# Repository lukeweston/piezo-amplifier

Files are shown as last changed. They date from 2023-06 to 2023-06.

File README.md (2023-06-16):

3-channel piezoelectric nanopositioning amplifier

Adapted from the design of Hwu et al, with a few small changes.

https://www.sciencedirect.com/science/article/pii/S2468067222000621#f0085

Changed to a commercially manufactured 2-layer PCB, as 2-layer professional PCBs are incredibly cheap and easily available today.
Made the PCB a little more compact.

Changed power amplifier ICs to LM1875 as they are more readily available.
Heatsinks need to be screwed onto the LM1875 amplifier tabs.

Changed to SMA connectors directly on the board, to more easily connect the outputs directly to the board.

Avoiding SMD components as much as possible, as science students (who aren't electronics specialists) often struggle with them.

PCB is 100mm x 80mm, 2 layers. Standard, cheap design rules like 6 thou / 6 thou will work fine.

The Zip file in this repo contains a standard, fabrication-ready set of Gerber files for a fab such as OSHPark or PCBWay.

Board and schematic (.brd / .sch files) are in Autodesk Eagle format.

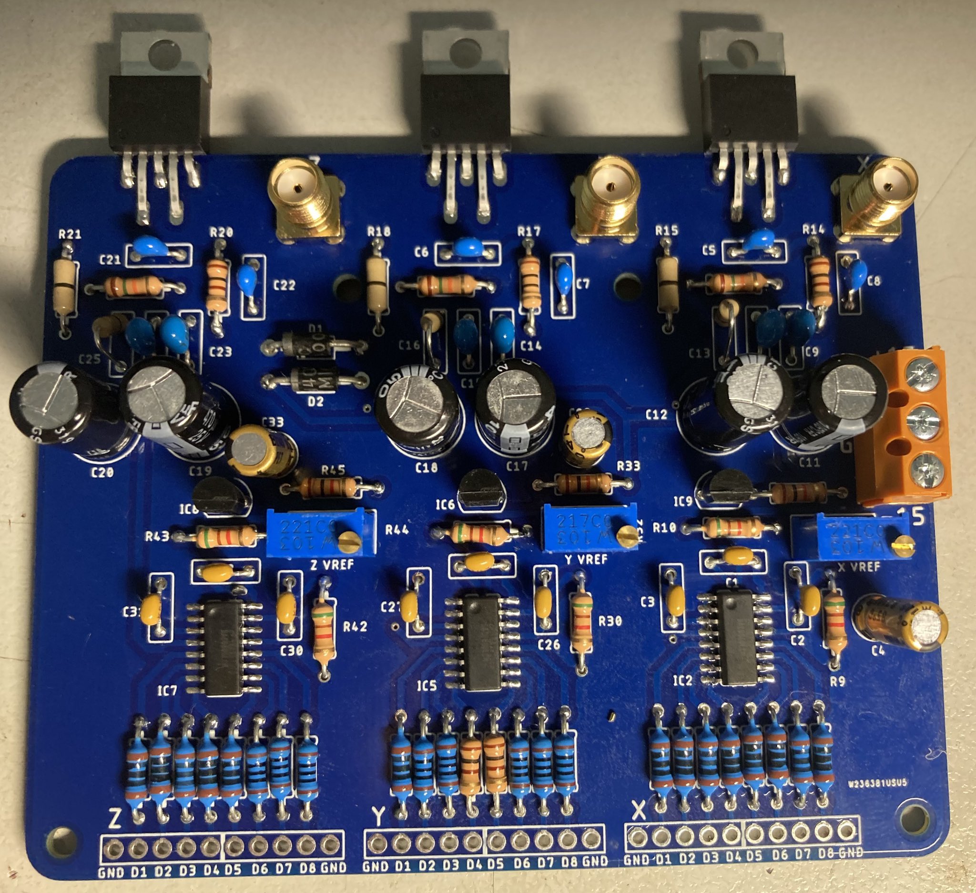
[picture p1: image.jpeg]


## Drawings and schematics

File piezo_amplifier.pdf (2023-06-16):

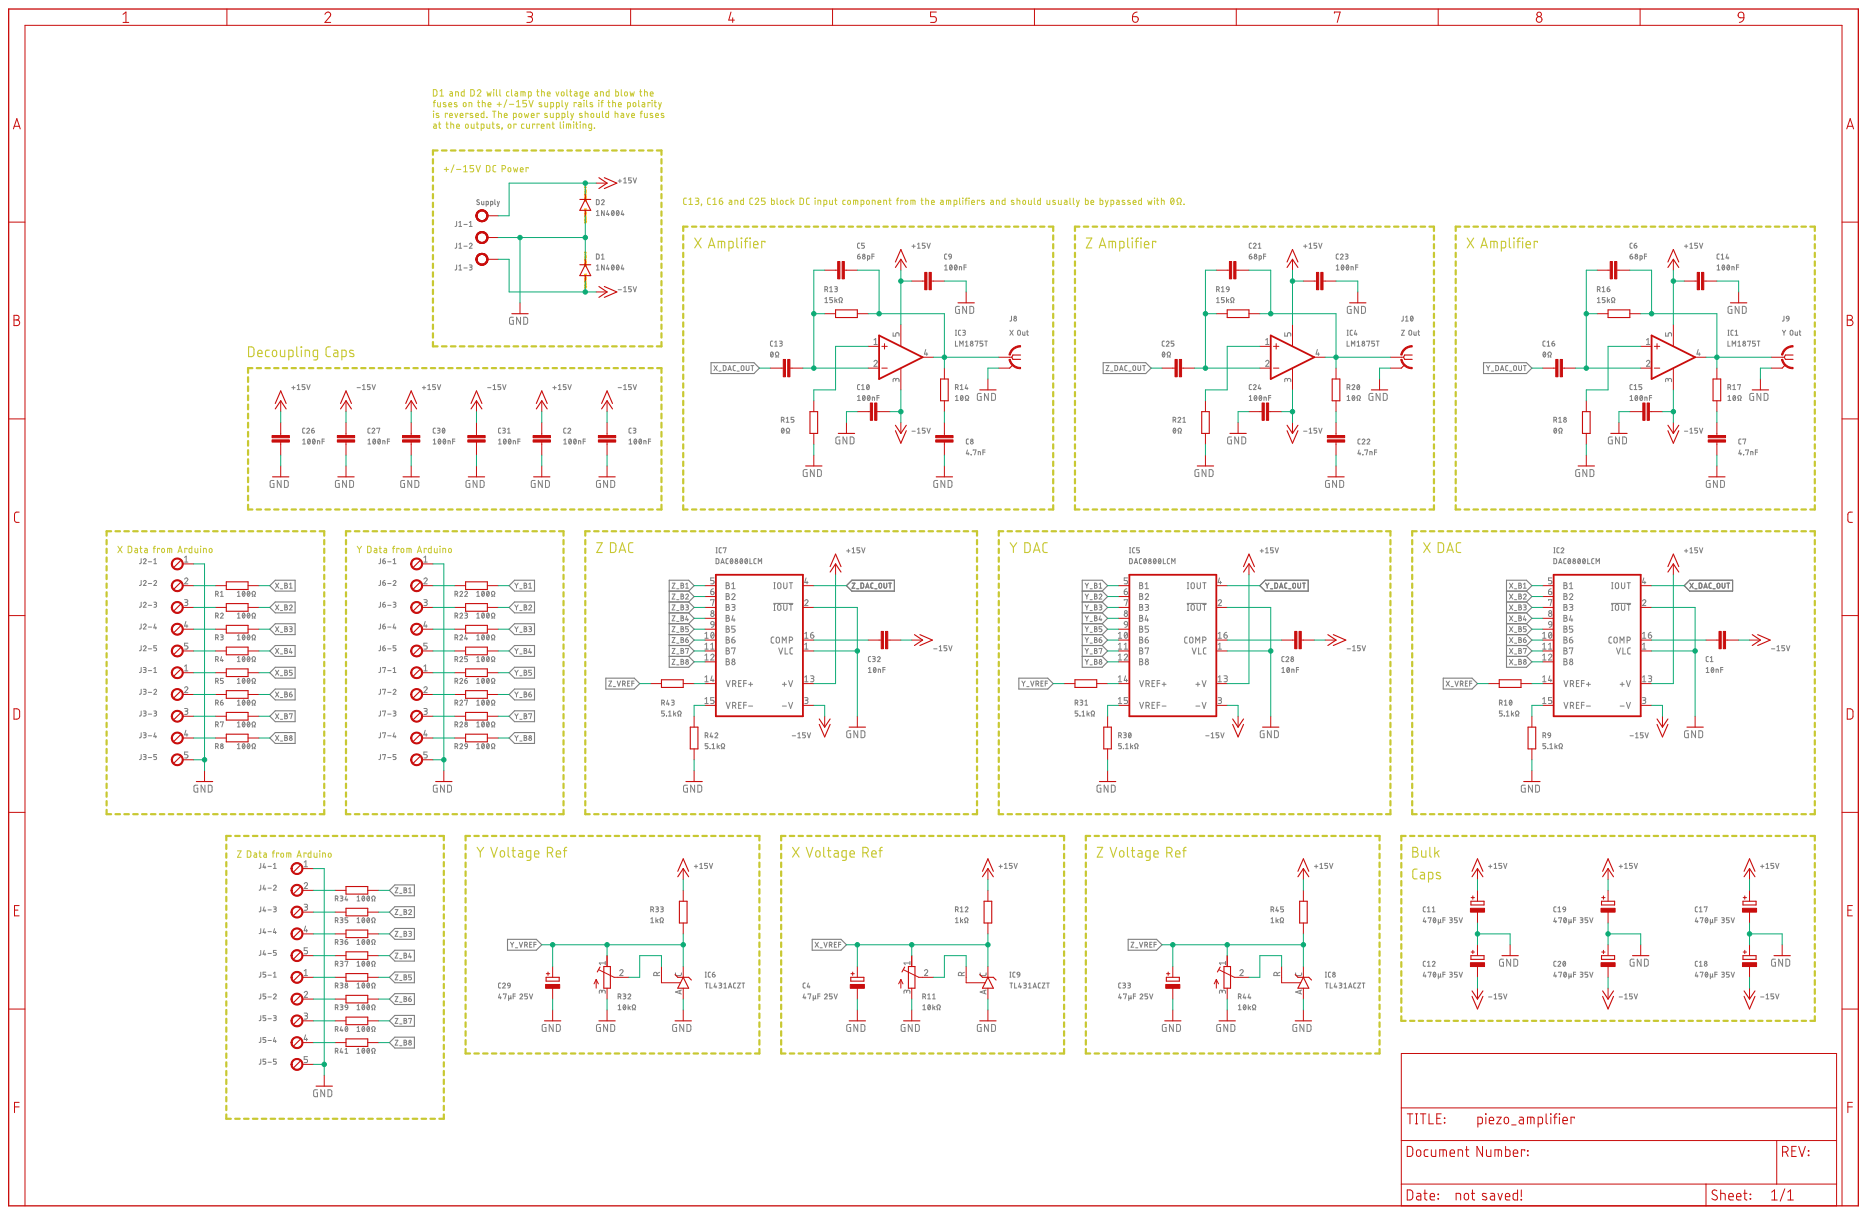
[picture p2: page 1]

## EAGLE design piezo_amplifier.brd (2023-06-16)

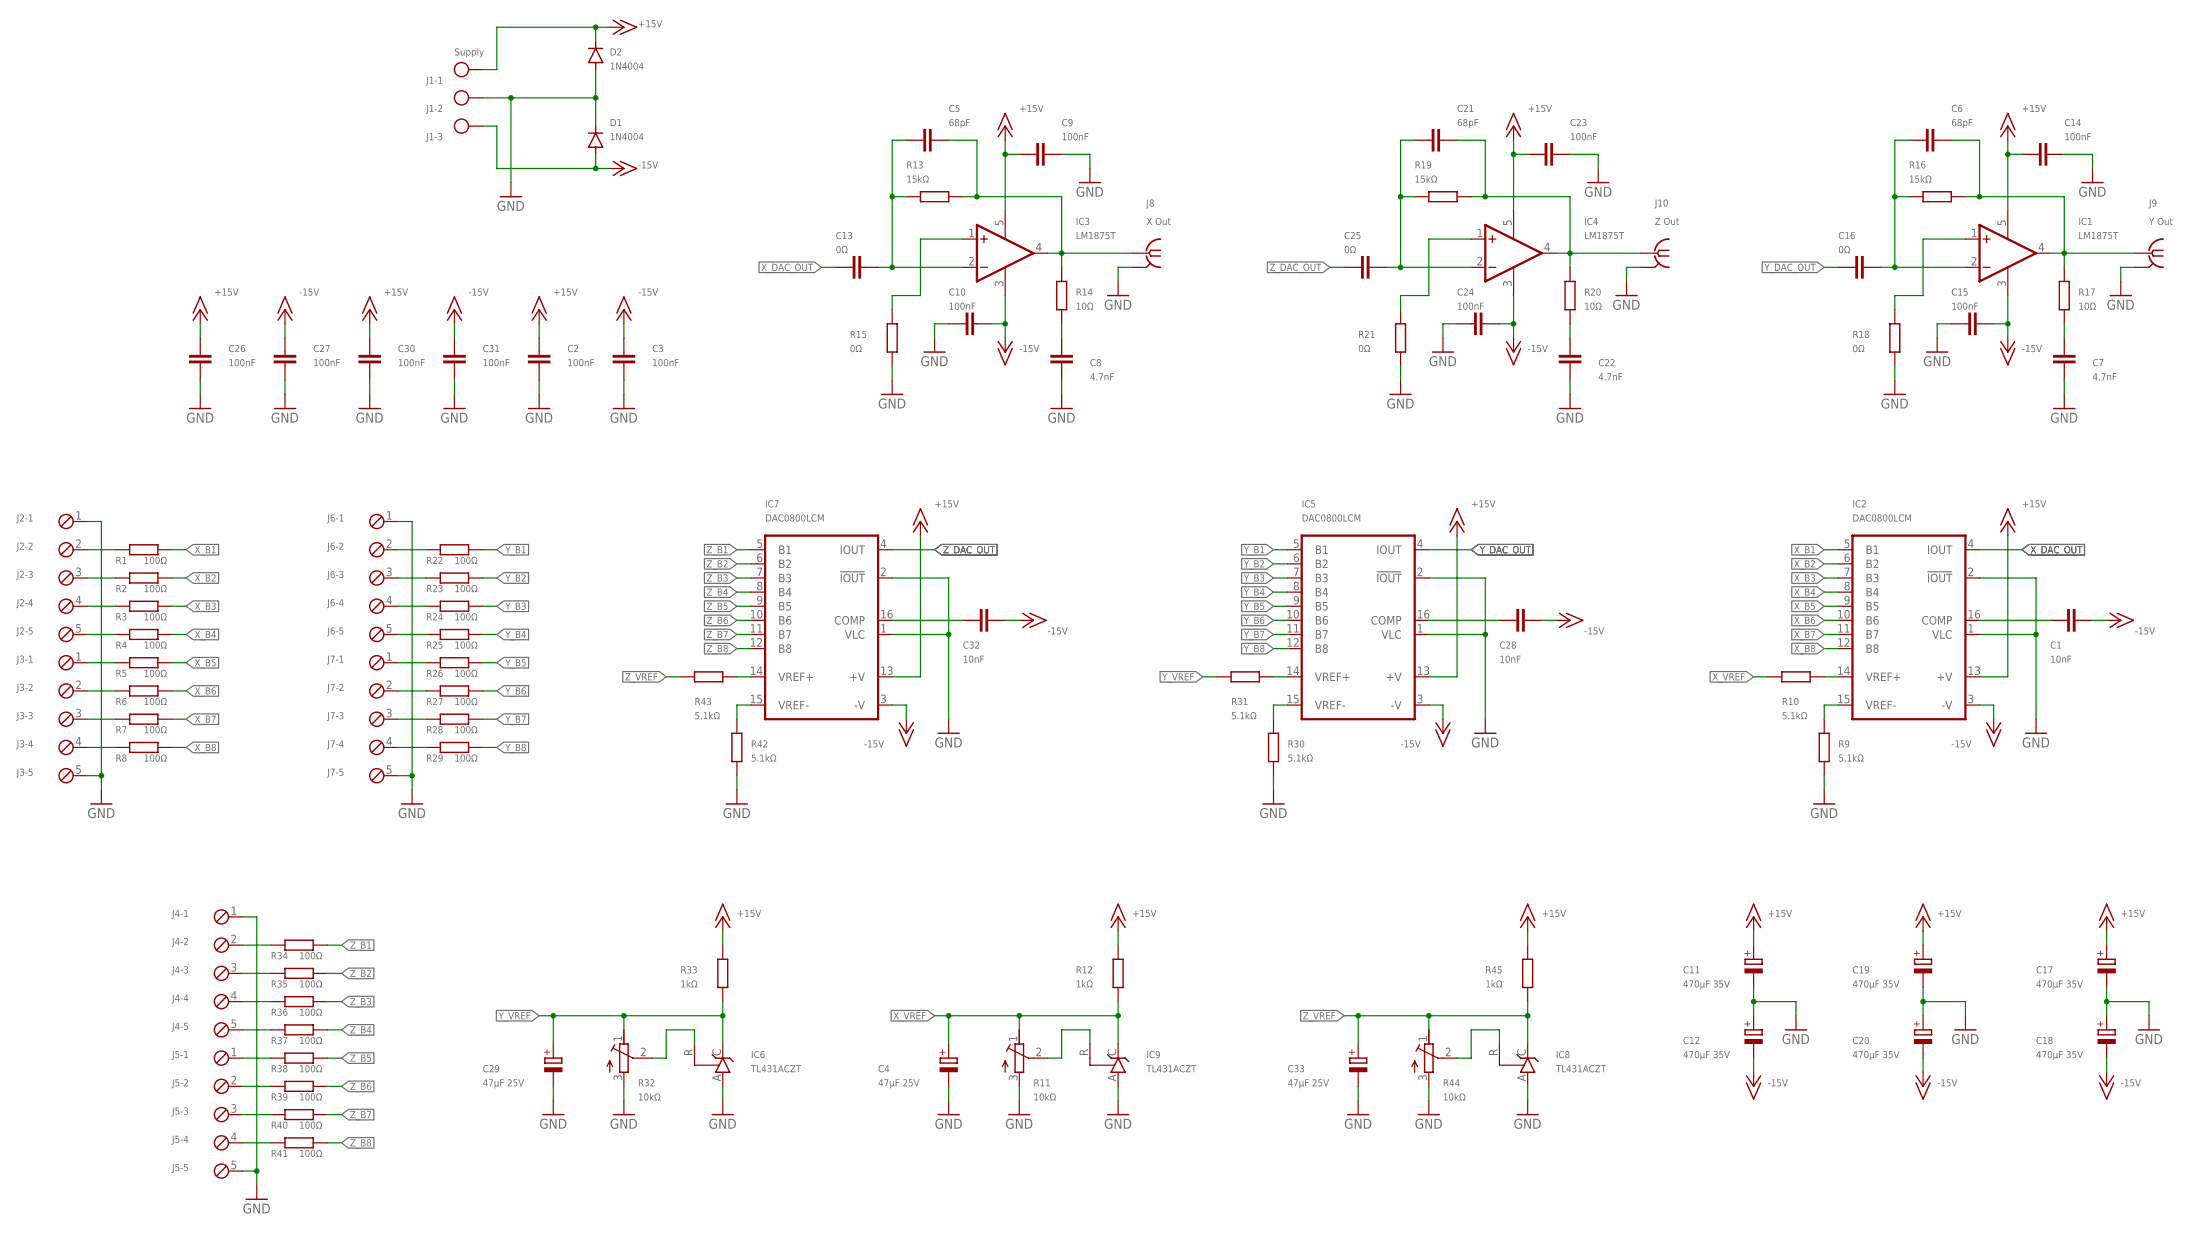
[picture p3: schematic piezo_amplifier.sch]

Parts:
C1, C28, C32: 10nF; C050-025X075
C2, C3, C9, C10, C14, C15, C23, C24, C26, C27, C30, C31: 100nF; C050-025X075
C4, C29, C33: 47µF 25V; E2,5-5
C5, C6, C21: 68pF; C050-025X075
C7, C8, C22: 4.7nF; C050-025X075
C11, C12, C17, C18, C19, C20: 470µF 35V; E5-8,5
C13, C16, C25: 0Ω; C050-025X075
D1, D2: 1N4004; DO41-10
IC1, IC3, IC4: LM1875T; CB367
IC2, IC5, IC7: DAC0800LCM; SO16
IC6, IC8, IC9: TL431ACZT; TO92-CLP
J1: Supply; MKDSN1,5/3-5,08
J2, J3, J4, J5, J6, J7: MPT5; 5POL254
J8: X Out; BU-SMA-V
J9: Y Out; BU-SMA-V
J10: Z Out; BU-SMA-V
R1, R2, R3, R4, R5, R6, R7, R8, R22, R23, R24, R25, R26, R27, R28, R29, R34, R35, R36, R37, R38, R39, R40, R41: 100Ω; 0207/10
R9, R10, R30, R31, R42, R43: 5.1kΩ; 0207/10
R11, R32, R44: 10kΩ; RTRIMT93YA
R12, R33, R45: 1kΩ; 0207/10
R13, R16, R19: 15kΩ; 0207/10
R14, R17, R20: 10Ω; 0207/10
R15, R18, R21: 0Ω; 0207/10

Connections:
+15V: C2.2, C9.1, C11.+, C14.1, C17.+, C19.+, C23.1, C26.2, C30.2, D2.C, IC1.5 (V+), IC2.13 (+V), IC3.5 (V+), IC4.5 (V+), IC5.13 (+V), IC7.13 (+V), J1.1, R12.2, R33.2, R45.2
-15V: C1.2, C3.2, C10.2, C12.-, C15.2, C18.-, C20.-, C24.2, C27.2, C28.2, C31.2, C32.2, D1.A, IC1.3 (V-), IC2.3 (-V), IC3.3 (V-), IC4.3 (V-), IC5.3 (-V), IC7.3 (-V), J1.3
FOO: C6.2, C16.1, IC1.2 (-IN), R16.2
FOO1: C21.2, C25.1, IC4.2 (-IN), R19.2
FOO2: C5.2, C13.1, IC3.2 (-IN), R13.2
GND: C2.1, C3.1, C4.-, C7.2, C8.2, C9.2, C10.1, C11.-, C12.+, C14.2, C15.1, C17.-, C18.+, C19.-, C20.+, C22.2, C23.2, C24.1, C26.1, C27.1, C29.-, C30.1, C31.1, C33.-, D1.C, D2.A, IC2.1 (VLC), IC2.2 (!IOUT), IC5.1 (VLC), IC5.2 (!IOUT), IC6.A, IC7.1 (VLC), IC7.2 (!IOUT), IC8.A, IC9.A, J1.2, J2.1, J3.5, J4.1, J5.5, J6.1, J7.5, J8.2, J8.3 (2), J8.4 (2), J8.5 (2), J9.2, J9.3 (2), J9.4 (2), J9.5 (2), J10.2, J10.3 (2), J10.4 (2), J10.5 (2), R9.1, R11.3 (A), R15.2, R18.2, R21.2, R30.1, R32.3 (A), R42.1, R44.3 (A)
unnamed: IC9.R, R11.2 (S)
unnamed: C5.1, IC3.4 (OUT), J8.1, R13.1, R14.2
unnamed: C6.1, IC1.4 (OUT), J9.1, R16.1, R17.2
unnamed: C8.1, R14.1
unnamed: IC3.1 (+IN), R15.1
unnamed: C7.1, R17.1
unnamed: IC1.1 (+IN), R18.1
unnamed: C21.1, IC4.4 (OUT), J10.1, R19.1, R20.2
unnamed: J2.3, R2.1
unnamed: J2.2, R1.1
unnamed: J2.4, R3.1
unnamed: J2.5, R4.1
unnamed: J3.1, R5.1
unnamed: J3.2, R6.1
unnamed: J3.3, R7.1
unnamed: J3.4, R8.1
unnamed: C22.1, R20.1
unnamed: IC4.1 (+IN), R21.1
unnamed: J6.2, R22.1
unnamed: J6.3, R23.1
unnamed: J6.4, R24.1
unnamed: J6.5, R25.1
unnamed: J7.1, R26.1
unnamed: J7.2, R27.1
unnamed: C1.1, IC2.16 (COMP)
unnamed: J7.3, R28.1
unnamed: J7.4, R29.1
unnamed: IC2.14 (VREF+), R10.1
unnamed: IC2.15 (VREF-), R9.2
unnamed: C28.1, IC5.16 (COMP)
unnamed: IC5.14 (VREF+), R31.1
unnamed: IC5.15 (VREF-), R30.2
unnamed: IC6.R, R32.2 (S)
unnamed: J4.2, R34.1
unnamed: J4.3, R35.1
unnamed: J4.4, R36.1
unnamed: J4.5, R37.1
unnamed: J5.1, R38.1
unnamed: J5.2, R39.1
unnamed: J5.3, R40.1
unnamed: J5.4, R41.1
unnamed: C32.1, IC7.16 (COMP)
unnamed: IC7.14 (VREF+), R43.1
unnamed: IC7.15 (VREF-), R42.2
unnamed: IC8.R, R44.2 (S)
X_B1: IC2.5 (B1), R1.2
X_B2: IC2.6 (B2), R2.2
X_B3: IC2.7 (B3), R3.2
X_B4: IC2.8 (B4), R4.2
X_B5: IC2.9 (B5), R5.2
X_B6: IC2.10 (B6), R6.2
X_B7: IC2.11 (B7), R7.2
X_B8: IC2.12 (B8), R8.2
X_DAC_OUT: C13.2, IC2.4 (IOUT)
X_VREF: C4.+, IC9.C, R10.2, R11.1 (E), R12.1
Y_B1: IC5.5 (B1), R22.2
Y_B2: IC5.6 (B2), R23.2
Y_B3: IC5.7 (B3), R24.2
Y_B4: IC5.8 (B4), R25.2
Y_B5: IC5.9 (B5), R26.2
Y_B6: IC5.10 (B6), R27.2
Y_B7: IC5.11 (B7), R28.2
Y_B8: IC5.12 (B8), R29.2
Y_DAC_OUT: C16.2, IC5.4 (IOUT)
Y_VREF: C29.+, IC6.C, R31.2, R32.1 (E), R33.1
Z_B1: IC7.5 (B1), R34.2
Z_B2: IC7.6 (B2), R35.2
Z_B3: IC7.7 (B3), R36.2
Z_B4: IC7.8 (B4), R37.2
Z_B5: IC7.9 (B5), R38.2
Z_B6: IC7.10 (B6), R39.2
Z_B7: IC7.11 (B7), R40.2
Z_B8: IC7.12 (B8), R41.2
Z_DAC_OUT: C25.2, IC7.4 (IOUT)
Z_VREF: C33.+, IC8.C, R43.2, R44.1 (E), R45.1

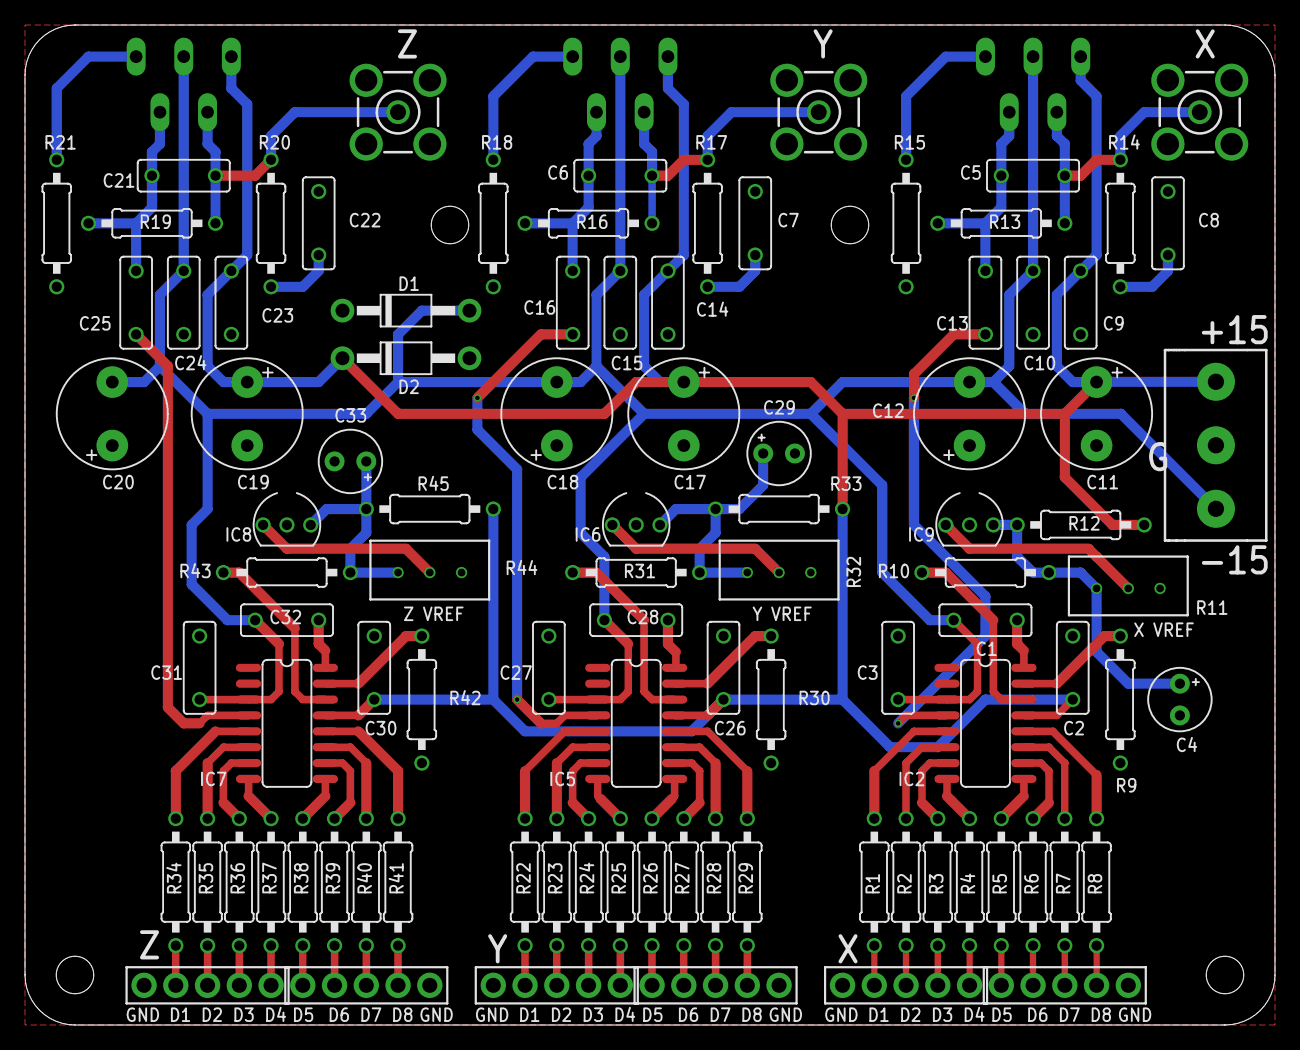
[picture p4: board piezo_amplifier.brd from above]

Board: 2 copper layers, 100.0 x 80.0 mm, 99 parts (0 on the bottom side), 81 nets.
